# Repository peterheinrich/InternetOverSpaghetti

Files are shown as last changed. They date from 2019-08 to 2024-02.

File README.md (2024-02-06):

# IP_Over_Spaghetti
Transmitting IP packages using two spaghetti as transport medium

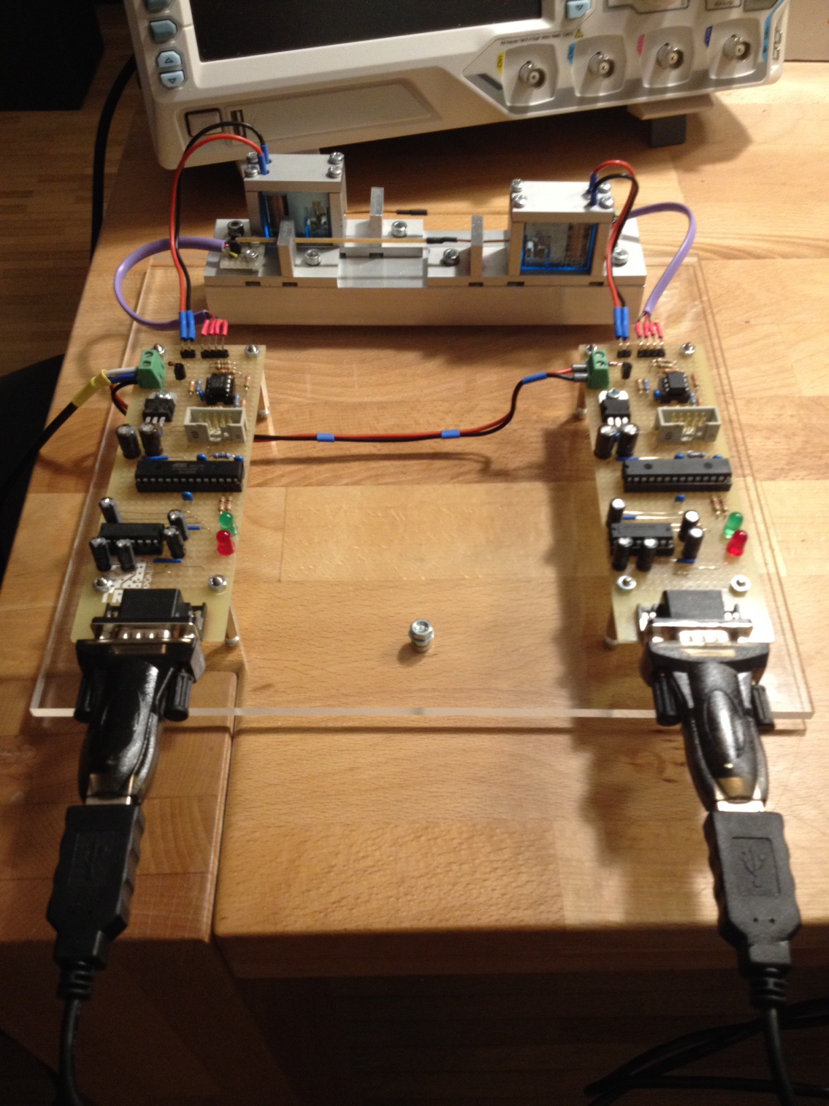
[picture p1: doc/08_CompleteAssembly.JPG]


Actually this is rather RS232 over spaghetti. But using the SLIP protocol, some USB-to-RS232 adapters and two Linux machines, one can easily tunnel IP over RS232, thus effectively tunneling IP over the spaghetti.

The whole chain looks like this:
SLIP(Linux) -> FTDI (USB<->RS232) -> ATMega328P -> Relais -> Spaghetti -> Optical Sensor -> ATMega328P -> FTDI (USB<->RS232) -> SLIP(Linux)

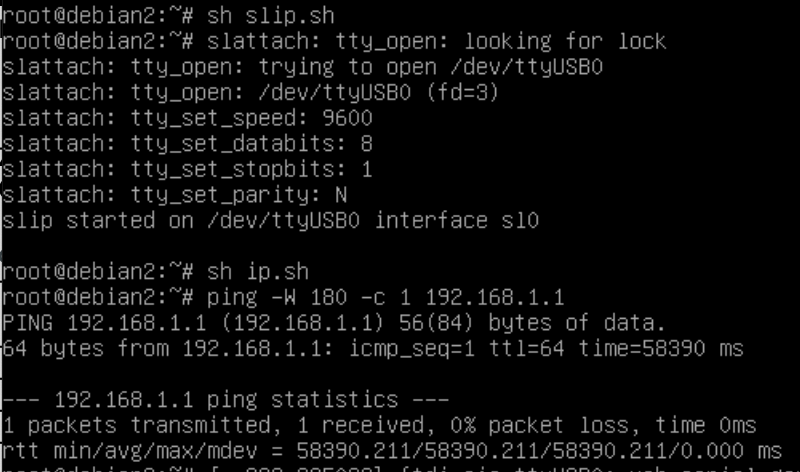
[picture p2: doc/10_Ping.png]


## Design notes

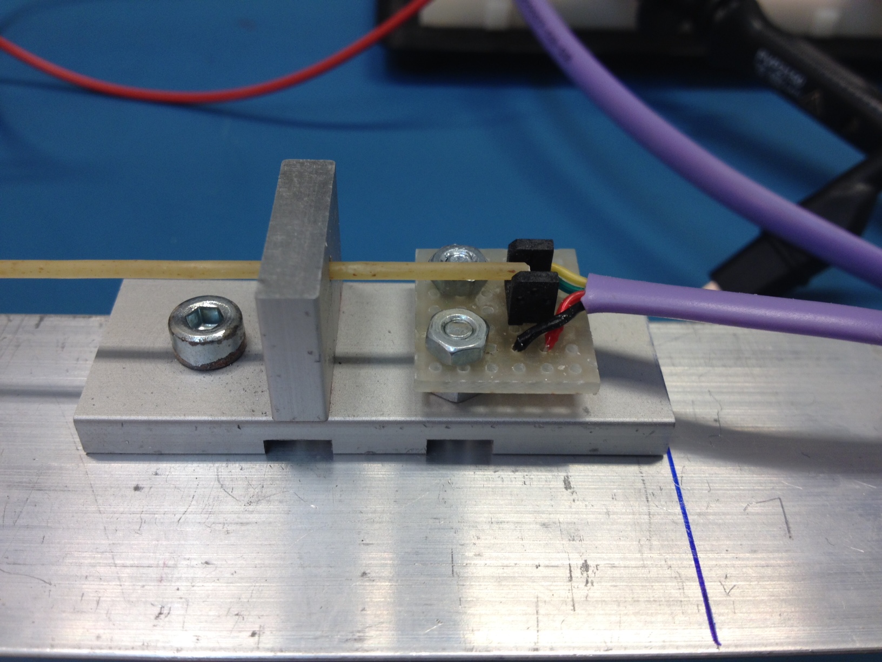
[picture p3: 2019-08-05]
doc/05_OpticalSensor.JPG

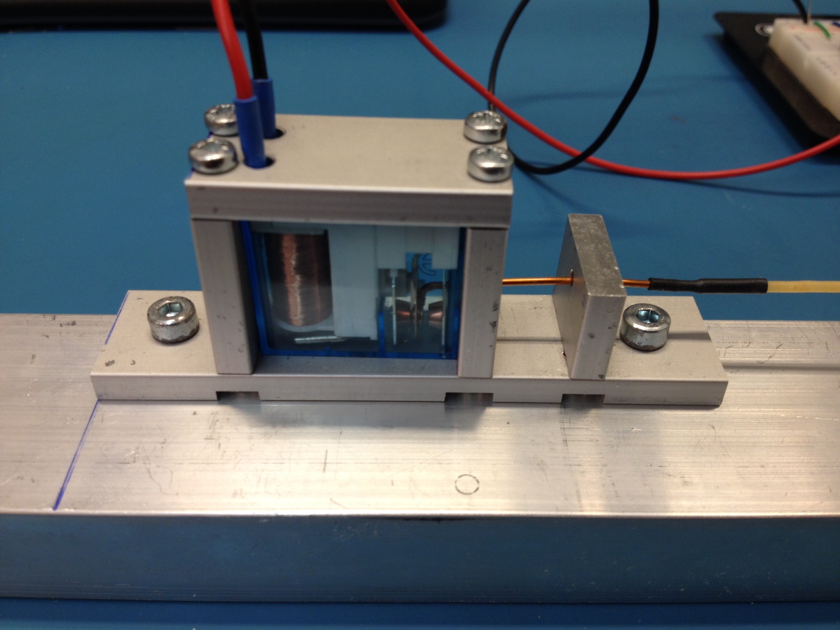
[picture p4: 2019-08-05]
doc/04_FinishedRelayDriver.JPG

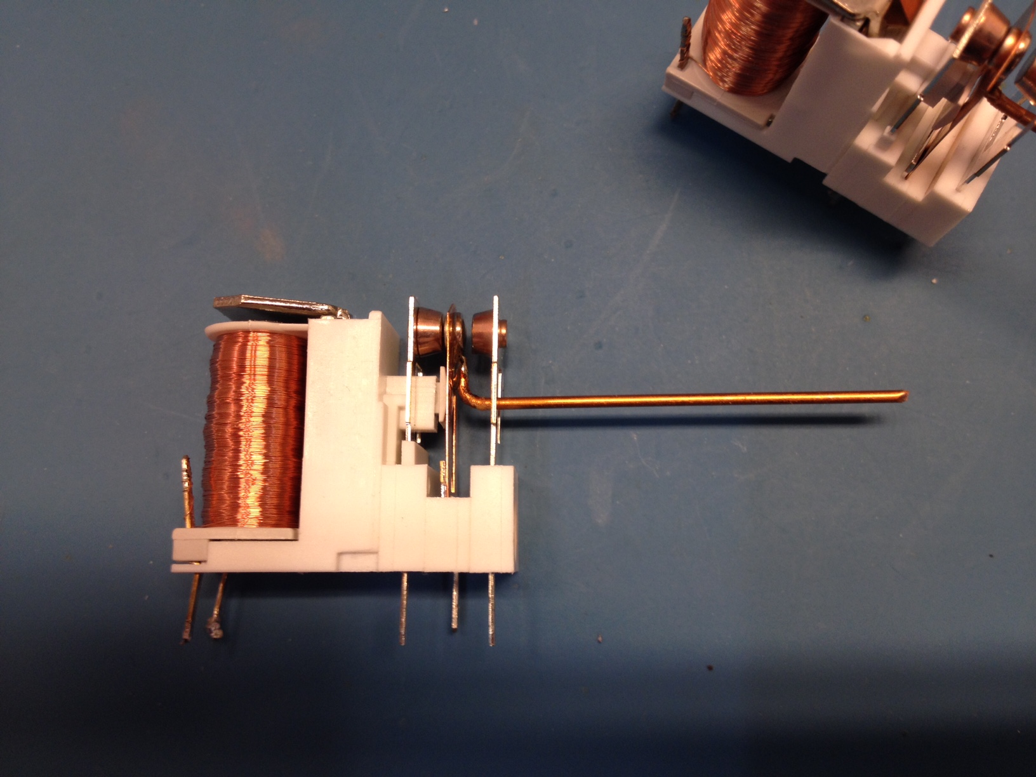
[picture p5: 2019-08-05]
doc/01_RelayModification.JPG

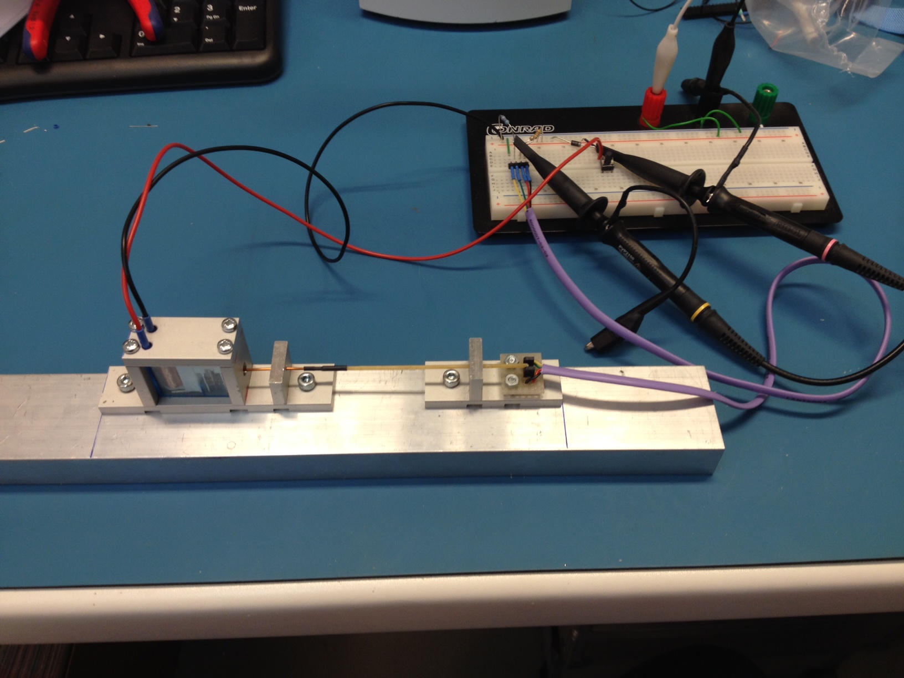
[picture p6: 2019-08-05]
doc/03_SingleChannelDemo.JPG

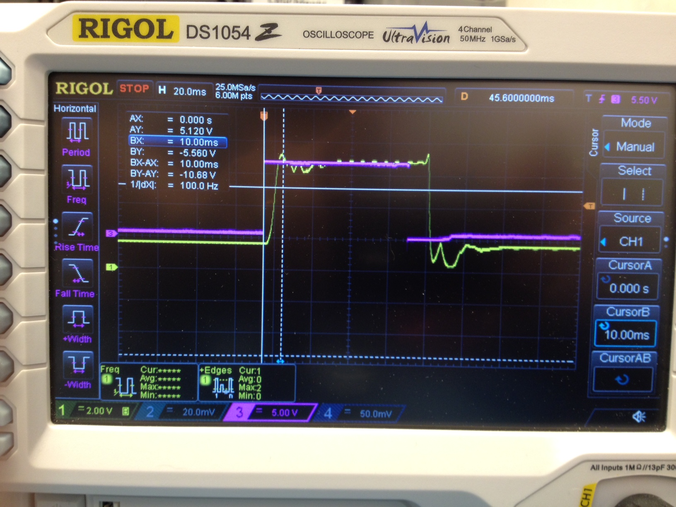
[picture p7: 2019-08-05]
doc/07_FilteredWaveform1Bit.JPG

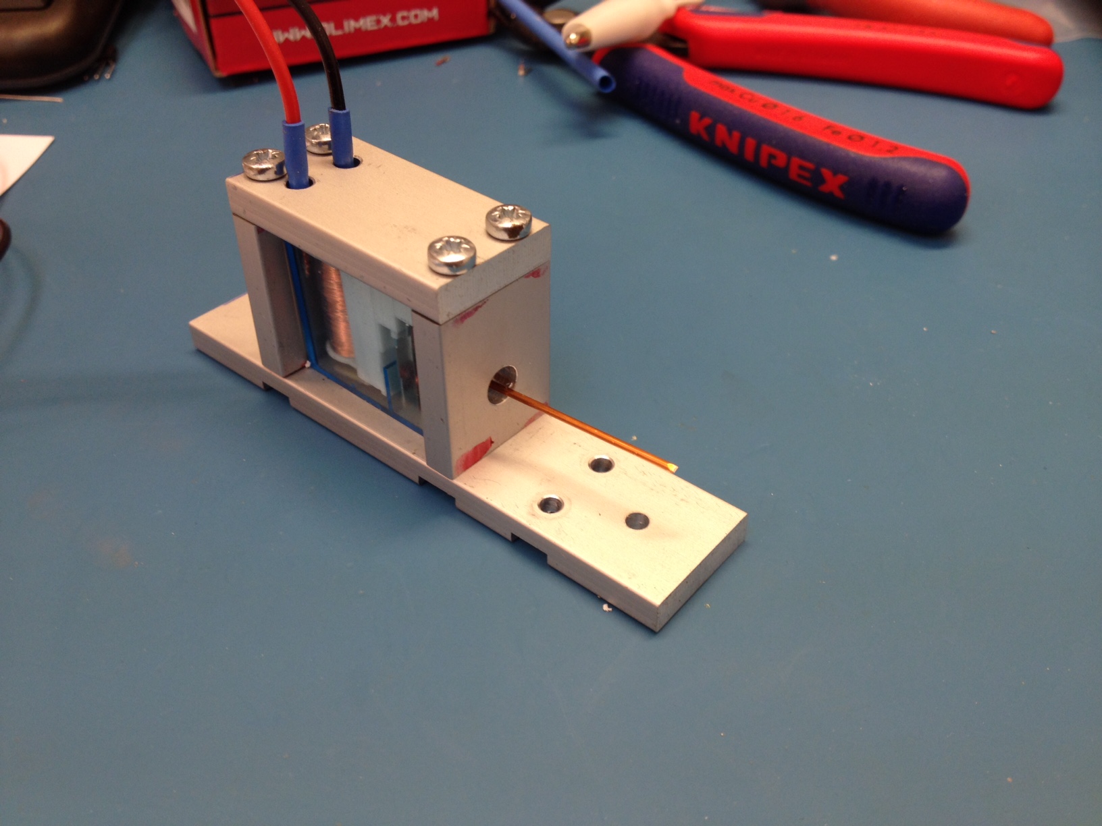
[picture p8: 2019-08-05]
doc/02_SpaghettiDriver.JPG

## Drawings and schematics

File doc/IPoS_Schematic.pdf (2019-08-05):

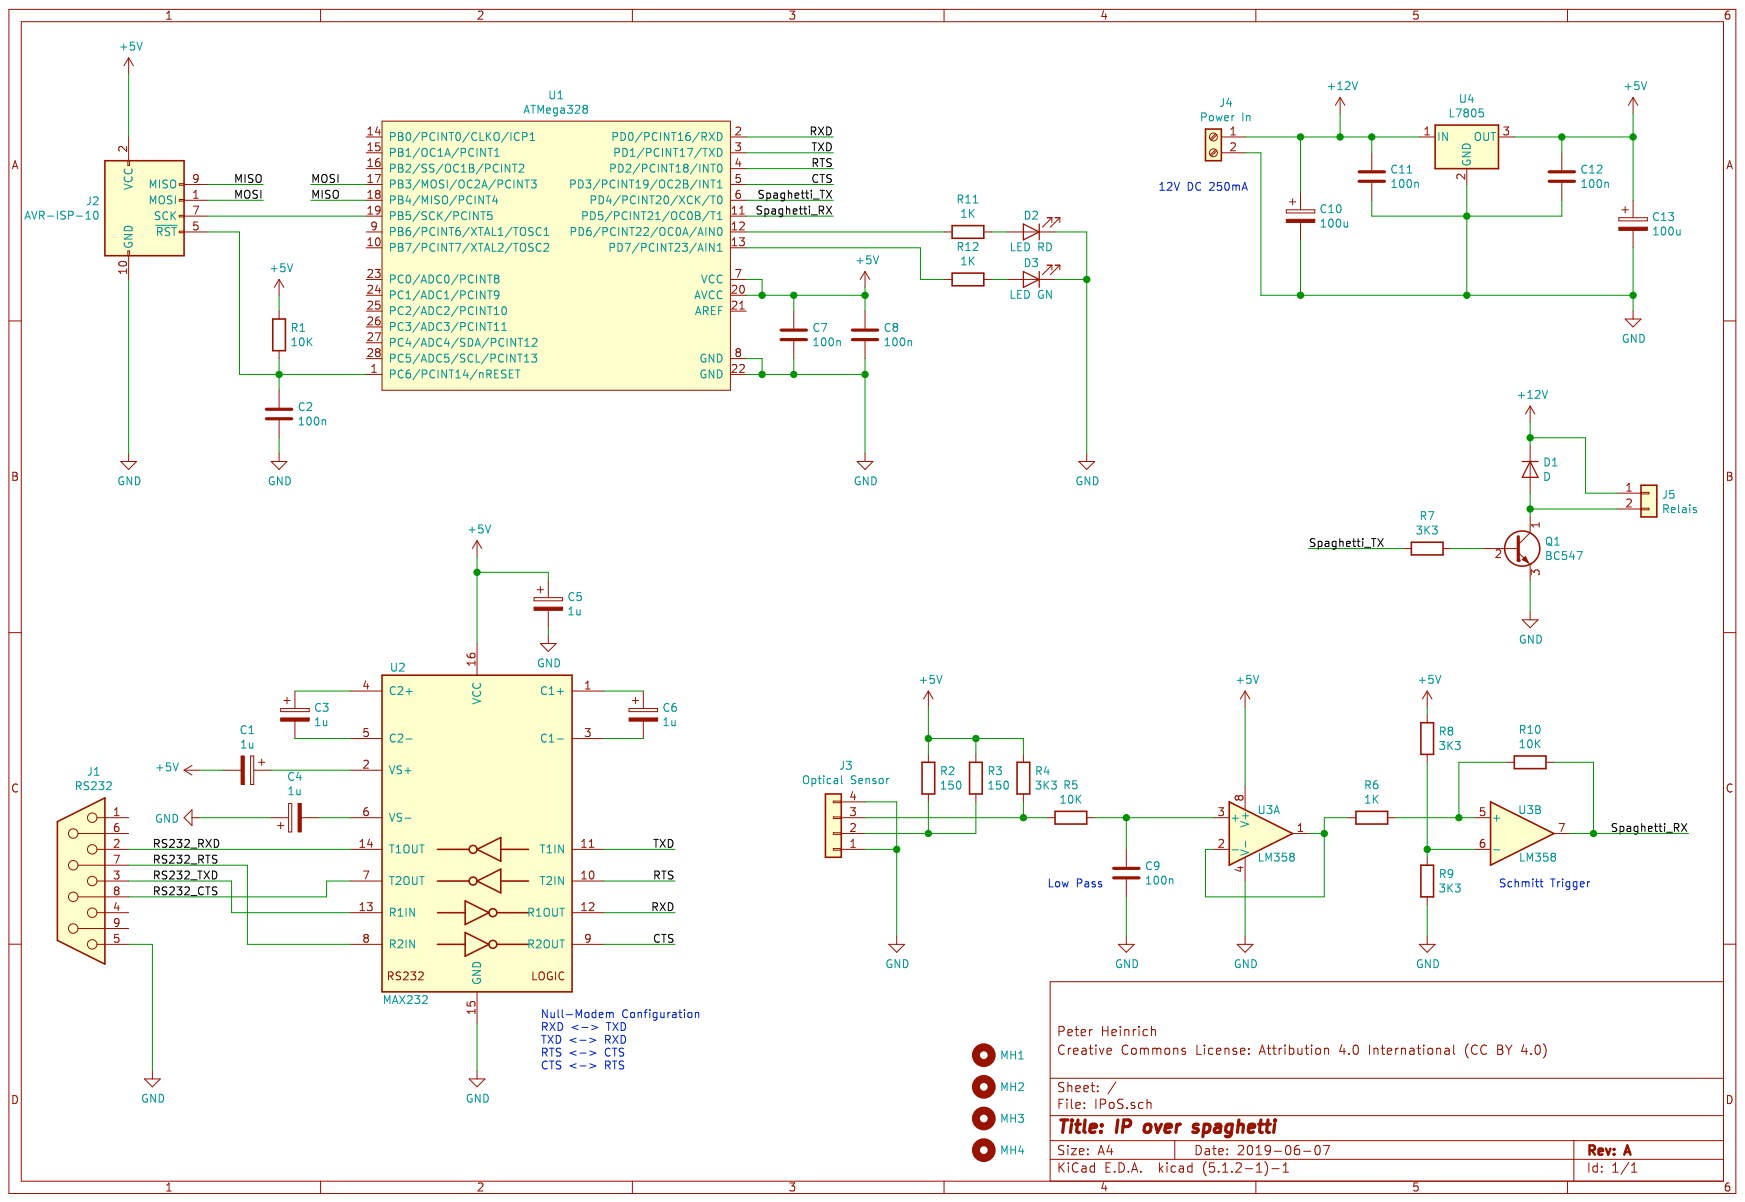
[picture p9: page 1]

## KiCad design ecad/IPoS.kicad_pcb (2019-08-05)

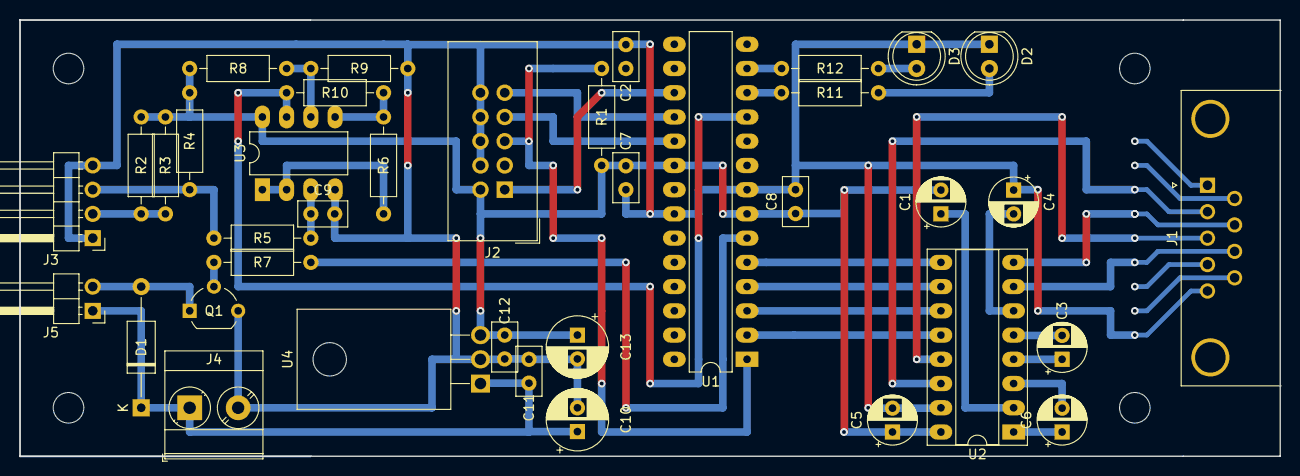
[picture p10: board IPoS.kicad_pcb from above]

Board: 2 copper layers, 132.1 x 45.7 mm, 42 parts (0 on the bottom side), 35 nets.

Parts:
C1, C3, C4, C5, C6: 1u; CP_Radial_D5.0mm_P2.50mm
C2, C7, C8, C9, C11, C12: 100n; C_Disc_D5.0mm_W2.5mm_P2.50mm
C10, C13: 100u; CP_Radial_D6.3mm_P2.50mm
D1: D; D_A-405_P12.70mm_Horizontal
D2: LED RD; LED_D5.0mm
D3: LED GN; LED_D5.0mm
J1: RS232; DSUB-9_Female_Horizontal_P2.77x2.84mm_EdgePinOffset4.94mm_H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
J2: AVR-ISP-10; IDC-Header_2x05_P2.54mm_Vertical
J3: Optical Sensor; PinHeader_1x04_P2.54mm_Horizontal
J4: Power In; TerminalBlock_Phoenix_MKDS-3-2-5.08_1x02_P5.08mm_Horizontal
J5: Relais; PinHeader_1x02_P2.54mm_Horizontal
MH1, MH2, MH3, MH4: MountingHole; MountingHole_3.2mm_M3
Q1: BC547; TO-92_Wide
R1, R5, R10: 10K; R_Axial_DIN0207_L6.3mm_D2.5mm_P10.16mm_Horizontal
R2, R3: 150; R_Axial_DIN0207_L6.3mm_D2.5mm_P10.16mm_Horizontal
R4, R7, R8, R9: 3K3; R_Axial_DIN0207_L6.3mm_D2.5mm_P10.16mm_Horizontal
R6, R11, R12: 1K; R_Axial_DIN0207_L6.3mm_D2.5mm_P10.16mm_Horizontal
U1: ATMega328; DIP-28_W7.62mm_LongPads
U2: MAX232; DIP-16_W7.62mm_Socket_LongPads
U3: LM358; DIP-8_W7.62mm_LongPads
U4: L7805; TO-220F-3_Horizontal_TabDown

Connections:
+5V: C1.2, C5.1, C7.1, C8.1, C12.1, C13.1, J2.2, R1.1, R2.1, R3.1, R4.1, R8.1, U1.7, U1.20, U2.16, U3.8, U4.3
+12V: C10.1, C11.1, D1.1, J4.1, J5.1, U4.1
/CTS: U1.5, U2.9
/MISO: J2.9, U1.18
/MOSI: J2.1, U1.17
/RS232_CTS: J1.8, U2.7
/RS232_RTS: J1.7, U2.8
/RS232_RXD: J1.2, U2.14
/RS232_TXD: J1.3, U2.13
/RTS: U1.4, U2.10
/RXD: U1.2, U2.12
/Spaghetti_RX: R10.1, U1.11, U3.7
/Spaghetti_TX: R7.2, U1.6
/TXD: U1.3, U2.11
GND: C2.2, C4.1, C5.2, C7.2, C8.2, C9.2, C10.2, C11.2, C12.2, C13.2, D2.1, D3.1, J1.5, J2.4, J2.6, J2.8, J2.10, J3.1, J3.4, J4.2, Q1.3, R9.2, U1.8, U1.22, U2.15, U3.4, U4.2
unnamed: C1.1, U2.2
unnamed: C2.1, J2.5, R1.2, U1.1
unnamed: C3.1, U2.4
unnamed: C3.2, U2.5
unnamed: C4.2, U2.6
unnamed: C6.1, U2.1
unnamed: C6.2, U2.3
unnamed: C9.1, R5.1, U3.3
unnamed: D1.2, J5.2, Q1.1
unnamed: D2.2, R11.1
unnamed: D3.2, R12.1
unnamed: J2.7, U1.19
unnamed: J3.2, R2.2, R3.2
unnamed: J3.3, R4.2, R5.2
unnamed: Q1.2, R7.1
unnamed: R6.2, U3.1, U3.2
unnamed: R8.2, R9.1, U3.6
unnamed: R6.1, R10.2, U3.5
unnamed: R11.2, U1.12
unnamed: R12.2, U1.13

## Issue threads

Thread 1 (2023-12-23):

Issue with Spaghetti Transmission Medium - Al Dente Required for Optimal Data Flow

Swwils, 2023-12-23:
I've encountered a rather perplexing issue, it appears that the integrity of our spaghetti-based transmission medium is directly correlated with its cooking time. As a firm believer in al dente pasta, I never imagined this preference would extend to networking protocols.

Upon further investigation, I discovered that undercooked spaghetti doesn't provide the necessary firmness for optimal signal integrity. Overcooked spaghetti, meanwhile, tends to get mushy, absorbing more data packets than it transmits.

**Proposed Solution:**
I propose we standardize the spaghetti cooking time to achieve an "al dente" state, ensuring a firm yet flexible data pathway. This might involve integrating a pasta timer into our setup or collaborating with Italian chefs for expert guidance.

**Additional Notes:**
While some might argue that using linguine or fettuccine could offer a wider bandwidth, I firmly believe in spaghetti's potential. After all, it's not about the size of the noodle but the consistency of the cook.

Bon Appétit

quite, 2023-12-28:
I came here to ask whether the spaghetti needed any preparation at all. So, al dente it is then!

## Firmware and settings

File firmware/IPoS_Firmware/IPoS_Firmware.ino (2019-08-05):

#include "TimerOne.h"  

#define SPAGHETTI_RX  5
#define SPAGHETTI_TX  4
#define LED_RED       6
#define LED_GREEN     7
#define CTS           3
#define RTS           2

#define BUFFSIZE      32
#define __DEBUG__

// Global variables need 'volatile' so that they can be altered within the ISR routine
volatile int tick = 0;

volatile char tx_buff[BUFFSIZE];
volatile char tx_buff_last = 0;
volatile char tx_byte = 0;
volatile char tx_state = 0;
volatile char tx_bit = 0;
volatile char tx_blank = 0;

volatile char rx_byte = 0;
volatile char rx_state = 0;
volatile char rx_bit = 0;
volatile char rx_tick_offset = 0;

/* ********************************************************************** */
/* *** BOARD SETUP                                                    *** */
/* ********************************************************************** */
void setup() {

  // Setup board specific pins
  pinMode(SPAGHETTI_TX, OUTPUT);
  pinMode(SPAGHETTI_RX, INPUT);
  pinMode(LED_RED, OUTPUT);
  pinMode(LED_GREEN, OUTPUT);
  pinMode(CTS, INPUT);
  pinMode(RTS, OUTPUT);

  // Simple 9600 8N1
  Serial.begin(9600); 

  // Assert RTS to accept incomming bytes
  digitalWrite(RTS,LOW);
  
  // Initialize 2.5ms timer interupt and register isr
  Timer1.initialize(2500);
  Timer1.attachInterrupt(isr_timer);

}


/* ********************************************************************** */
/* *** MAIN 400Hz INTERRUPT ROUTINE                                    *** */
/* ********************************************************************** */
void isr_timer() {
  int i;

  /* ********************************************************************** */
  /* *** TRANSMIT                                                       *** */
  /* ********************************************************************** */

  // Check if buffer is full. If buffer is full it is better to lose bytes than to crash ...
  if (Serial.available() > 0 && tx_buff_last < BUFFSIZE - 1) {
    tx_buff[tx_buff_last] = Serial.read() & 0xFF;
    tx_buff_last++;
  } 

  // Some implementation take several bytes until they react on RTS deassertion. Thus, we accept only 4 bytes before deasserting RTS.
  if(tx_buff_last > 3) {
      digitalWrite(RTS,HIGH);
  }
  else {
      digitalWrite(RTS,LOW);
  }

  // A single bit is exactly 25ms long. Thus, we switch states every 10 timer ticks.
  if(tick % 10 == 0) {
    switch(tx_state) {
      case 0:
       // If buffer is nonempty, remove and transmit first byte from buffer
        if(tx_buff_last > 0) {
          tx_byte = tx_buff[0];
          // move all items to the front - yes, dumb but simple! No need for a ringbuffer whatsoever!
          for(i = 1; i < tx_buff_last; i++) {
            tx_buff[i-1] = tx_buff[i];
          }
          tx_buff_last --;
          tx_state = 1;
          tx_bit = 0;
        }
        break;
      case 1:
        // Write the start bit
        digitalWrite(SPAGHETTI_TX,HIGH);
        tx_state = 2;
        break;
      case 2:
        // Write individual bits
        digitalWrite(SPAGHETTI_TX,(tx_byte >> tx_bit) & 0x01);
        tx_bit++;
        if(tx_bit > 7) {
          tx_blank = 0;
          tx_state = 3;
          tx_bit = 0;
        }
        break;
      case 3:
        // Insert a two cycle blank
        digitalWrite(SPAGHETTI_TX,LOW);
        if(tx_blank > 1) {
          tx_state = 0;
        }
        tx_blank ++;
        break;
    }   
  }

  /* ********************************************************************** */
  /* *** RECEIVE                                                        *** */
  /* ********************************************************************** */
  
  // We scan for the start bit on any tick (400Hz)
  if(rx_state == 0) {
    if(digitalRead(SPAGHETTI_RX)) {

#ifdef __DEBUG__
      digitalWrite(LED_RED,HIGH);
      delay(1);
      digitalWrite(LED_RED,LOW);
#endif

      rx_state = 1;
      rx_byte = 0x0;
      rx_bit = 0;
      // We store the offset to the 25ms bit cycle and add some margin to scan for the next bits roughly in the middle of their heigh period.
      rx_tick_offset = ((tick + 6) % 10);  
    }
  }
  
  if(rx_state != 0 && tick % 10 == rx_tick_offset) {
    switch(rx_state) {
      case 1:
        // Waiting for the start bit to clear (dummy state)
        rx_state = 2;
        break;
      case 2:
      
#ifdef __DEBUG__  
        digitalWrite(LED_GREEN,HIGH);
        delay(1);
        digitalWrite(LED_GREEN,LOW);
#endif
        // Reading all the bits
        rx_byte = rx_byte | (digitalRead(SPAGHETTI_RX) << rx_bit);       
        rx_bit ++;
        
        if(rx_bit > 7) {
          Serial.write(rx_byte);
          rx_state = 3;
        }
        break;
      case 3:
        // Waiting for last transferred bit to clear (dummy state)
        rx_state = 0;
        rx_bit = 0;
        break;
    }   
  }

  /* ********************************************************************** */
  /* *** HOUSE KEEPING                                                  *** */
  /* ********************************************************************** */

  // Increment tick counter and roll over
  tick ++;
  if(tick >= 1000) tick = 0;
}

// Nothing left to be done. Just an empty loop ...
void loop() {
    
}

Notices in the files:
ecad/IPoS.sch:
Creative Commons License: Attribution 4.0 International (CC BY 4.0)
